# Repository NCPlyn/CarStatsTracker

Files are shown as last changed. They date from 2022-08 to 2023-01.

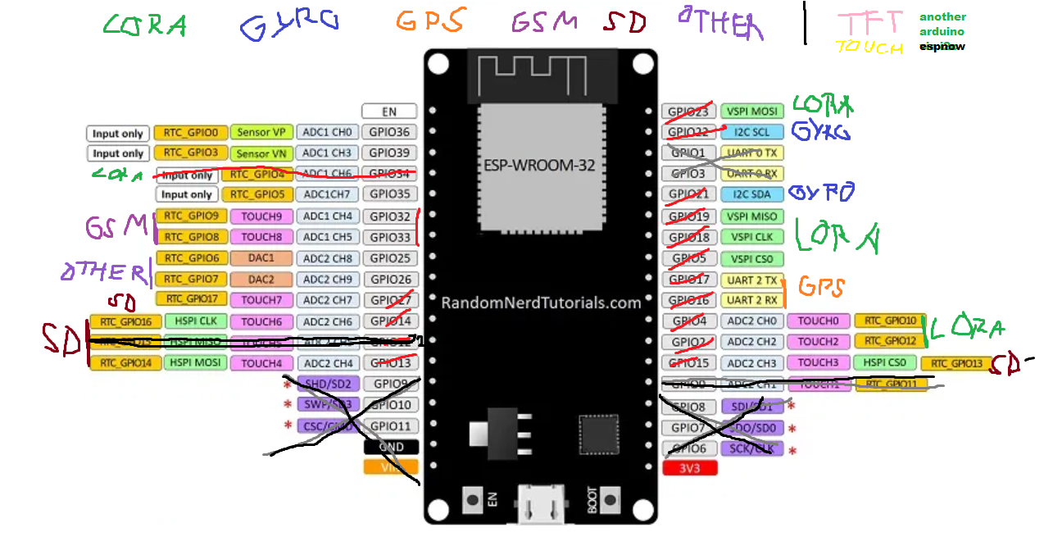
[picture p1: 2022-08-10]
PCB/pins.png

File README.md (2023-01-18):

# CarStatsTracker
Závěrečná práce\
Pro více informací použijte [dokumentaci](Dokumentace.pdf)

## Cíl projektu

Cílem projektu je vyrobit zařízení které:
- Sleduje polohu zařízení/auta pomocí GPS a posílá tyto údaje přes LoRaWAN nebo GSM na server.
- Je možno na mapě zobrazit projeté trasy s naměřenou rychlostí v bodech, ať již na serveru či lokálně na ESP.
- Možnost zjištění rychlosti akcelerace s přesností až na 200ms pomocí GPS (0-100kmph,0-60mph,1/4mile.... nastavitelné)
- Nahrání neodeslaných dat po připojení k internetu přes WiFi
- Popř. vyžádání aktuální lokace pomocí SMS zprávy a multithreading

## Použitý hardware

- ESP32 Development Board
- RA-01SH SX1276 LoRa module
- NEO-6M GPS module
- LSM6DS3 Akcelerometr module
- SD Card module, GSM module a napájecí moduly

## Použitý software a dokumentace
- LoRaWAN pro SX1276: https://github.com/beegee-tokyo/SX126x-Arduino
- TinyGPS++ pro NEO-6M: http://arduiniana.org/libraries/tinygpsplus/
- ESPAsyncWebServer pro lokání web: https://github.com/me-no-dev/ESPAsyncWebServer
- Hlavní server (Debian VPS) funguje na základě https://nodejs.org/
- spolu s základními express a socket.io knihoven, pro mapy je využit https://leafletjs.com/
- a další knihovny pro ESP\

- Byly použity návody z https://randomnerdtutorials.com/
- Dále příklady využití jednotlivých knihoven
- ArduinoJson dokumentace
- Kód z jiného projektu (https://github.com/NCPlyn/ProtogenHelmet-ESP32 & https://github.com/NCPlyn/Lidl4chan)
- Kód pro konvertování unix času (https://github.com/GyverLibs/UnixTime/blob/main/src/UnixTime.h)
- Kód pro zasunutí objektu do array (https://stackoverflow.com/questions/38418921/insert-json-object-to-ordered-array-in-javascript)
- HTTPS Wifi POST (https://github.com/espressif/arduino-esp32/tree/master/libraries/WiFiClientSecure)
- OpenSSL (https://serverfault.com/questions/845766/generating-a-self-signed-cert-with-openssl-that-works-in-chrome-58)
- MQTT pro TTN (https://youtu.be/hxIKyFAgZCE)
- EasyEDA pro vytvoření schématu a PCB

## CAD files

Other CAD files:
PCB/boxcts.f3d

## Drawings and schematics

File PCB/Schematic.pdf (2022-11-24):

LM2596

1 In +

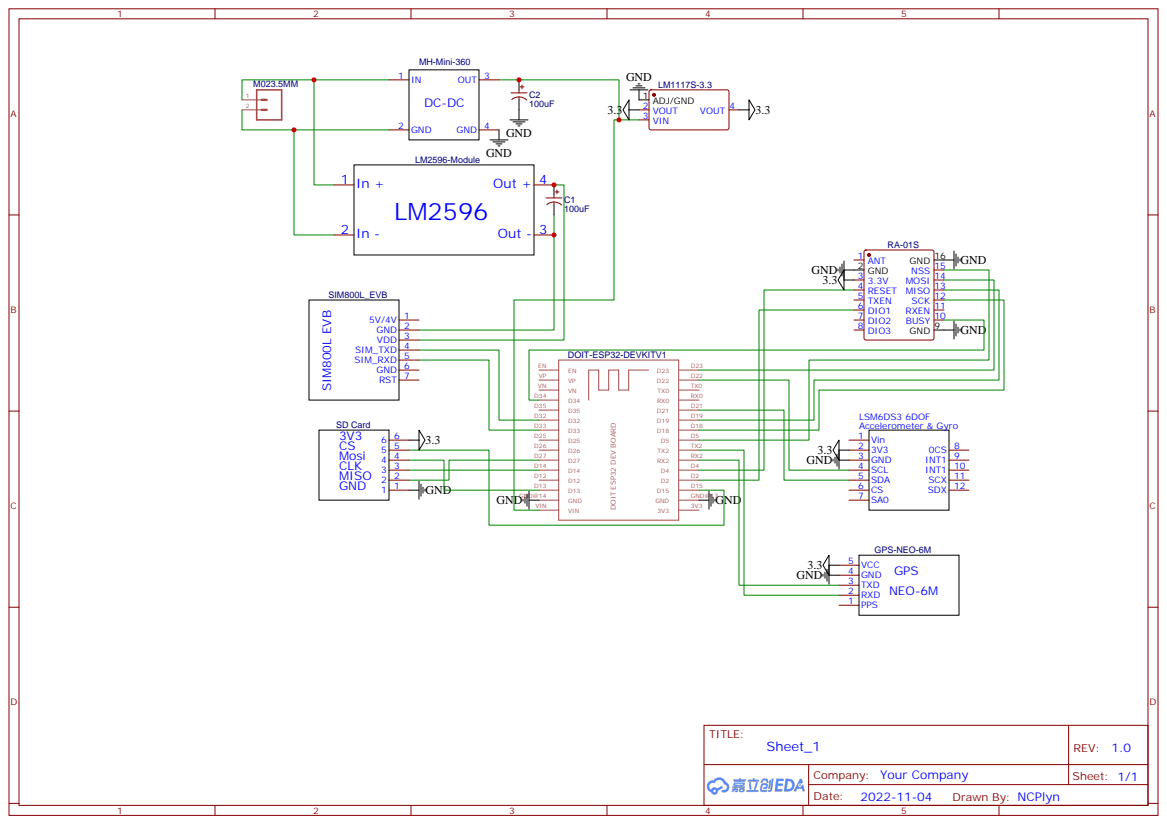
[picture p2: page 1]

BUSY 10 RXEN 11 SCK 12 MISO 13 MOSI 14 NSS 15 GND 16

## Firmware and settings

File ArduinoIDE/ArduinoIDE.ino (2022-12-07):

#include <Arduino.h>
#include <sstream>
#include <WiFi.h>
#include <HTTPClient.h>
#include <WiFiClientSecure.h>
#include <AsyncTCP.h>
#include <ESPAsyncWebServer.h>
#include "SparkFunLSM6DS3.h"
#include "Wire.h"
#include "SPI.h"
#include <TinyGPS++.h>
#include <ArduinoJson.h>
#include <ArduinoSort.h>
#include <LoRaWan-Arduino.h>
#define CONFIG_LITTLEFS_SPIFFS_COMPAT 1
#include <LittleFS.h>
#include "loraCreds.h"
#include "FS.h"
#include "SD.h"

//------------------SD CARD------------------//
#define SD_CS 15
#define SPI_SCK 14
#define SPI_MISO 27
#define SPI_MOSI 13
SPIClass SPISD(HSPI);
//Also to properly work, add "VSPI" to the () in 'SX126x-Arduino\src\boards\mcu\espressif\spi_board.cpp' on line 5

//------------------LORA------------------//
#define LORAWAN_APP_DATA_BUFF_SIZE 50 // Size of the data to be transmitted
#define JOINREQ_NBTRIALS 3  // Number of trials for the join request
hw_config hwConfig;
// Foward declaration
static void lorawan_has_joined_handler(void);
static void lorawan_join_failed_handler(void);
static void lorawan_rx_handler(lmh_app_data_t *app_data); //předdefinové, nepoužité
static void lorawan_confirm_class_handler(DeviceClass_t Class); //--||--
static void send_lora_frame(String toSend);
static uint8_t m_lora_app_data_buffer[LORAWAN_APP_DATA_BUFF_SIZE]; // Lora user application data buffer.
static lmh_app_data_t m_lora_app_data = {m_lora_app_data_buffer, 0, 0, 0, 0}; // Lora user application data structure.
static lmh_param_t lora_param_init = {LORAWAN_ADR_ON, DR_3, LORAWAN_PUBLIC_NETWORK, JOINREQ_NBTRIALS, LORAWAN_DEFAULT_TX_POWER, LORAWAN_DUTYCYCLE_OFF}; //Structure containing LoRaWan parameters, needed for lmh_init()
static lmh_callback_t lora_callbacks = {BoardGetBatteryLevel, BoardGetUniqueId, BoardGetRandomSeed, lorawan_rx_handler, lorawan_has_joined_handler, lorawan_confirm_class_handler, lorawan_join_failed_handler};//Structure containing LoRaWan callback functions, needed for lmh_init()

uint8_t nodeDeviceEUI[8], nodeAppEUI[8];
uint8_t nodeAppKey[16], nodeNwsKey[16], nodeAppsKey[16];
uint32_t nodeDevAddr;

void copyArrays() {
  memcpy(nodeDeviceEUI,STOREDnodeDeviceEUI,sizeof(STOREDnodeDeviceEUI));
  memcpy(nodeAppEUI,STOREDnodeAppEUI,sizeof(STOREDnodeAppEUI));
  memcpy(nodeAppKey,STOREDnodeAppKey,sizeof(STOREDnodeAppKey));
  memcpy(nodeNwsKey,STOREDnodeNwsKey,sizeof(STOREDnodeNwsKey));
  memcpy(nodeAppsKey,STOREDnodeAppsKey,sizeof(STOREDnodeAppsKey));
}

int loraStatus = 0; //0 off, 1 joined, 2 failed

//------------------WiFi & Web------------------//
String apName = "CST";
String apPass = "1234567890";
String staName = "todo";
String staPass = "todo";
String webAddress = "example.com/uplink";

WiFiClientSecure wifiClient;
HTTPClient httpsClient;

unsigned long wifiInterval = 0;

int lastUploaded = 0;

AsyncWebServer server(80);

void notFound(AsyncWebServerRequest *request) {
  request->send(404, "text/plain", "Not found");
}

//------------------GPS & IMU ------------------//
TinyGPSPlus gps;
TinyGPSCustom gpsFix(gps, "GPGGA", 6);

LSM6DS3 myIMU;

//------------------Variable declaration------------------//
volatile float deadzoneX=0,deadzoneY=0,deadzoneZ=0;

volatile int opMode = 0; //0 - normal, 1 - drag
int currentRideID = 0, currentDragID = 0;
bool enaLora = true; //false - GSM
float detectVal=0.4;

//------Drag------
volatile int numOfSpeeds = 0;
volatile int targetSpeeds[30] = {10};
volatile double targetSpeedsTime[30], targetSpeedsDist[30];

volatile int numOfDistances = 0;
volatile int targetDistances[30] = {100};
volatile double targetDistancesTime[30];

volatile bool dragging = false, doDrag = false, dEnded = false;
volatile double startLat = 0, startLng = 0;
volatile unsigned long startTime = 0, startTimeGPS = 0;

String dragJson;
int lastUploadedDrag = 0;

//------Normal------
unsigned long detectMoveMillis = millis(), lastLora = millis();
bool detectMove = true, moveDetected = false, routeActive = false, gpsReady = false, firstLora = true;
int retryMoveDetect = 0, didntMove = 0, loraReductor = 0;
double lastLat = 48.85826, lastLng = 2.294516;

//------Forward Declare------
void sendPos(String moving);
void calibrateAcc();
void modeSwitch(int opm);
void processDrag(bool web, char *out, unsigned long startTime, double startLat, double startLng);
void dragTimer();
void LoraSetup();

bool loadSPIFFS() {
  DynamicJsonDocument doc(512);

  File file = LittleFS.open("/config.json", "r");
  if (!file) {
    Serial.println("There was an error opening the config file!");
    file.close();
    return false;
  }
  Serial.println("Config file opened!");

  DeserializationError error = deserializeJson(doc, file);
  if (error){
    Serial.println("Failed to deserialize the config file!");
    file.close();
    return false;
  }
  file.close();

  currentRideID = doc["currentRideID"].as<int>();
  currentDragID = doc["currentDragID"].as<int>();
  lastUploaded = doc["lastUploaded"].as<int>();
  lastUploadedDrag = doc["lastUploadedDrag"].as<int>();
  enaLora = doc["enaLora"].as<bool>();
  detectVal = doc["detectVal"].as<float>();
  apName = doc["apName"].as<String>();
  apPass = doc["apPass"].as<String>();
  staName = doc["staName"].as<String>();
  staPass = doc["staPass"].as<String>();
  webAddress = doc["webAddress"].as<String>();
  return true;
}

bool saveSPIFFS() {
  DynamicJsonDocument doc(512);

  File file = LittleFS.open("/config.json", "w");
  if (!file) {
    Serial.println("There was an error opening the config file!");
    file.close();
    return false;
  }
  Serial.println("Config file opened!");

  doc["currentRideID"] = currentRideID;
  doc["currentDragID"] = currentDragID;
  doc["lastUploaded"] = lastUploaded;
  doc["lastUploadedDrag"] = lastUploadedDrag;
  doc["enaLora"] = enaLora;
  doc["detectVal"] = detectVal;
  doc["apName"] = apName;
  doc["apPass"] = apPass;
  doc["staName"] = staName;
  doc["staPass"] = staPass;
  doc["webAddress"] = webAddress;

  if (serializeJson(doc, file) == 0) {
    Serial.println("Failed to deserialize the config file");
    file.close();
    return false;
  }
  file.close();

  return true;
}

void setup() {
  Serial.begin(115200);
  delay(1000);
  Serial.println("Processor came out of reset.\n");

  if (!LittleFS.begin(true)) {
    Serial.println("An Error has occurred while mounting LittleFS");
  }

  loadSPIFFS();

  for(int x = 0;x<numOfSpeeds;x++) {
    targetSpeedsTime[x] = 0;
  }
  for(int x = 0;x<numOfDistances;x++) {
    targetDistancesTime[x] = 0;
  }

  pinMode(SD_CS, OUTPUT);
  SPISD.begin(SPI_SCK, SPI_MISO, SPI_MOSI);
  if(!SD.begin(SD_CS,SPISD)){
    Serial.println("Card Mount Failed");
  } else {
    Serial.printf("Used space: %lluMB\n", SD.usedBytes() / (1024 * 1024));
  }

  myIMU.begin();

  Serial2.begin(115200, SERIAL_8N1, 16, 17); //RX 16, TX 17

  pinMode(0, INPUT);

  WiFi.mode(WIFI_MODE_APSTA);
  WiFi.softAP(apName.c_str(), apPass.c_str());
  Serial.println(WiFi.softAPIP());
  WiFi.setAutoReconnect(false);

  server.serveStatic("/", LittleFS, "/").setDefaultFile("index.html");

  server.on("/opmode", HTTP_GET, [](AsyncWebServerRequest *request){
    if(request->hasParam("val")) {
      modeSwitch(request->getParam("val")->value().toInt());
      if(request->getParam("val")->value().toInt() == 0) {
        request->redirect("/");
      } else {
        request->redirect("/drag.html");
      }
    }
    request->send(200, "text/plain", "No param 'val'");
  });
  server.on("/doDrag", HTTP_POST, [](AsyncWebServerRequest *request){
    if(opMode == 1 && gpsReady && !doDrag && request->hasParam("json", true)) {
      calibrateAcc();
      for(int x = 0;x<30;x++){
        targetSpeeds[x] = 0;
        targetSpeedsTime[x] = 0;
        targetSpeedsDist[x] = 0;
        targetDistances[x] = 0;
        targetDistancesTime[x] = 0;
      }
      //get json and put it in global string
      dragJson = request->getParam("json", true)->value();
      //parse
      DynamicJsonDocument doc(2048);
      DeserializationError error = deserializeJson(doc, dragJson);
      if (error){
        Serial.println("Failed to deserialize json");
        request->send(200, "text/plain", "Failed to deserialize json");
      }
      //for each speed get 'target', write it to the array
      //doc["speed"][i]["targ"].as<int>()
      numOfDistances = 0;
      JsonArray distanceArray = doc["dist"];
      for (JsonObject t : distanceArray) {
        targetDistances[numOfDistances] = t["targ"].as<int>();
        numOfDistances++;
      }
      sortArray(targetDistances, numOfDistances);
      //do same for distance
      numOfSpeeds = 0;
      JsonArray speedArray = doc["speed"];
      for (JsonObject t : speedArray) {
        targetSpeeds[numOfSpeeds] = t["targ"].as<int>();
        numOfSpeeds++;
      }
      sortArray(targetSpeeds, numOfSpeeds);
      startTimeGPS = 0;
      dEnded = false;
      doDrag = true;
      Serial.println(doDrag); //musí se to přečíst nebo delay nebo co??
      request->send(200, "text/plain", "Waiting for movement/forced command");
    } else if (opMode == 0) {
      request->send(200, "text/plain", "Not in drag mode");
    } else if (!gpsReady) {
      request->send(200, "text/plain", "GPS not ready: age("+String(gps.location.age())+"), fix("+String(gpsFix.value())+"), sats("+String(gps.satellites.value())+")");
    } else {
      request->send(200, "text/plain", "Drag already in progress or other.");
    }
  });
  server.on("/forceDragStop", HTTP_GET, [](AsyncWebServerRequest *request){
    dragging = false;
    request->send(200);
  });
  server.on("/forceDragStart", HTTP_GET, [](AsyncWebServerRequest *request){
    if(opMode == 1 && gpsReady && doDrag) {
      dragTimer();
      request->send(200);
    } else if (opMode == 0) {
      request->send(200, "text/plain", "not in drag mode");
    } else if (!gpsReady) {
      request->send(200, "text/plain", "GPS not ready: age("+String(gps.location.age())+"), fix("+String(gpsFix.value())+"), sats("+String(gps.satellites.value())+")");
    } else if (!doDrag) {
      request->send(200, "text/plain", "Didn't start drag (it will sent needed data).");
    } else {
      request->send(200, "text/plain", "Drag already in progress or other.");
    }
  });
  server.on("/calibrate", HTTP_GET, [](AsyncWebServerRequest *request){
    calibrateAcc();
    request->send(200, "text/plain", "ok");
  });
  server.on("/getSpeed", HTTP_GET, [](AsyncWebServerRequest *request){
    if(gpsReady) {
      request->send(200, "text/plain", String(gps.speed.kmph()) + " km/h");
    } else {
      request->send(200, "text/plain", "GPS not ready");
    }
  });
  server.on("/getProcDrag", HTTP_GET, [](AsyncWebServerRequest *request){
    char proccesed[2048];
    processDrag(true, proccesed, startTimeGPS, startLat, startLng);
    request->send(200, "text/plain", proccesed);
  });
  server.on("/lora", HTTP_GET, [](AsyncWebServerRequest *request){
    if(request->hasParam("join")) {
      if(loraStatus == 2) {
        lmh_join();
        request->redirect("/config.html");
      } else {
        request->send(200, "text/plain", "Lora is either joined already or not initialized!");
      }
    }
    request->send(200, "text/plain", String(loraStatus));
  });
  server.on("/wifi", HTTP_GET, [](AsyncWebServerRequest *request){
    if(request->hasParam("join")) {
      if(WiFi.status() != WL_CONNECTED) {
        WiFi.disconnect();
        WiFi.begin(staName.c_str(), staPass.c_str());
        wifiInterval = millis();
        request->redirect("/config.html");
      } else {
        request->send(200, "text/plain", "WiFi is in different status than WL_CONNECTED!");
      }
    }
    request->send(200, "text/plain", String(WiFi.status()));
  });
  server.on("/getfile", HTTP_GET, [](AsyncWebServerRequest *request){
    if(request->hasParam("rideid")) {
      String path = "/"+request->getParam("rideid")->value()+".data";
      Serial.printf("Reading file: %s\n", path);
      File file = SD.open(path);
      if(!file){
          Serial.println("Failed to open file for reading");
          return;
      }
      String dataFileContents;
      while(file.available()){
          dataFileContents += (char)file.read();
      }
      file.close();
      request->send(200, "text/plain", dataFileContents);
    } else {
      request->send(200, "text/plain", "Parameter 'rideid' not present!");
    }
  });
  server.on("/getfiles", HTTP_GET, [](AsyncWebServerRequest *request){
    String out;
    File root = SD.open("/");
    if(!root){
        Serial.println("Failed to open directory");
        return;
    }

    File file = root.openNextFile();
    while(file){
        if(!file.isDirectory()){
          out += String(file.name())+";";
        }
        file = root.openNextFile();
    }
    request->send(200, "text/plain", out);
  });
  server.on("/saveconfig", HTTP_GET, [](AsyncWebServerRequest *request){ //saves config
    if(request->hasParam("enaLora"))
      std::istringstream(request->getParam("enaLora")->value().c_str()) >> std::boolalpha >> enaLora;
    if(request->hasParam("currentRideID"))
      currentRideID = request->getParam("currentRideID")->value().toInt();
    if(request->hasParam("currentDragID"))
      currentDragID = request->getParam("currentDragID")->value().toInt();
    if(request->hasParam("lastUploaded"))
      staPass = String(request->getParam("lastUploaded")->value());
    if(request->hasParam("lastUploadedDrag"))
      staPass = String(request->getParam("lastUploadedDrag")->value());
    if(request->hasParam("detectVal"))
      detectVal = String(request->getParam("detectVal")->value()).substring(0, 4).toFloat();
    if(request->hasParam("apName"))
      apName = String(request->getParam("apName")->value());
    if(request->hasParam("apPass"))
      apPass = String(request->getParam("apPass")->value());
    if(request->hasParam("staName"))
      staName = String(request->getParam("staName")->value());
    if(request->hasParam("staPass"))
      staPass = String(request->getParam("staPass")->value());
    if(request->hasParam("webAddress"))
      webAddress = String(request->getParam("webAddress")->value());
    if(saveSPIFFS()) {
      ESP.restart();
      request->redirect("/");
    } else {
      request->send(200, "text/plain", "Saving config failed!");
    }
  });

  server.onNotFound(notFound);
  server.begin();

  File file = LittleFS.open("/certificate.pem", "r");
  if (!file) {
    Serial.println("There was an error opening the certificate file!");
    file.close();
  } else {
    wifiClient.loadCACert(file,file.size());
  }

  calibrateAcc();

  if(enaLora) {
    copyArrays();
    LoraSetup();
  } else {
    //GSM init
  }
}

void loop()
{
  //GPS Serial decode
  while (Serial2.available() > 0) {
    if (gps.encode(Serial2.read())) {
      if(!gps.location.isValid() || gps.location.age() > 2000 || gpsFix.value() == 0 || gps.satellites.value() < 2) {
        gpsReady = false;
      } else {
        gpsReady = true;
      }
    }
  }

  //Main routines
  if(opMode == 0) {
    //If not moving, data to SD every 6 minutes (360000) & lora every 30 minutes (loraReductor)
    if(gpsReady && !routeActive && (millis()>lastLora+360000 || (firstLora && loraStatus == 1))) {
      Serial.println("sending not move data");
      if(firstLora && loraStatus == 1) {
        firstLora = false;
        loraReductor = 0;
        delay(200);
      }
      sendPos("n");
      lastLora = millis();
    }

    //Try to connect to WiFi & LoRa every 10 minutes (600000)
    if(millis()>(wifiInterval+600000)) {
      wifiInterval = millis();
      if(WiFi.status() != WL_CONNECTED) {
        Serial.println("Reconnecting to WiFi...");
        WiFi.disconnect();
        WiFi.begin(staName.c_str(), staPass.c_str());
      }
      if(loraStatus == 2 && enaLora) {
        lmh_join();
      }
    }

    if(WiFi.status() == WL_CONNECTED && enaLora && !routeActive ) {
      File file;
      if(lastUploaded < currentRideID) {
        file = SD.open("/"+String(lastUploaded+1)+".data");
        lastUploaded++;
        saveSPIFFS();
      } else if (lastUploadedDrag < currentDragID) {
        file = SD.open("/d"+String(lastUploadedDrag+1)+".data");
        lastUploadedDrag++;
        saveSPIFFS();
      }
      if(file){
        httpsClient.begin(wifiClient, "https://"+webAddress);
        while(file.available()){
          httpsClient.setAuthorization("admin", "admin");
          httpsClient.addHeader("Content-Type", "text/plain");
          String data = file.readStringUntil('\n');
          httpsClient.addHeader("Content-Length", String(data.length()));
          Serial.println(httpsClient.POST(data));
        }
        file.close();
        httpsClient.end();
      } else if (lastUploaded == currentRideID || lastUploadedDrag == currentDragID) {
        //do nothing
      } else {
        Serial.println("Failed to open file to send data");
      }
    }

    if(detectMove && ((myIMU.readFloatAccelX()-deadzoneX)>detectVal || (myIMU.readFloatAccelY()-deadzoneY)>detectVal || (myIMU.readFloatAccelZ()-deadzoneZ)>detectVal || (gps.speed.kmph()>5 && gpsReady))) {
      Serial.println("Movement detected");
      moveDetected = true;
      detectMove = false;
      retryMoveDetect = 0, didntMove = 0;
      detectMoveMillis = millis();
    }
    if(millis()>(detectMoveMillis+10000) && moveDetected) {
      Serial.println(gps.speed.kmph());
      if(gpsReady && gps.speed.kmph() > 5) {
        Serial.println("We movin");
        routeActive = true;
        moveDetected = false;
        currentRideID++;
        saveSPIFFS();
      } else {
        if(retryMoveDetect < 3) {
          retryMoveDetect++;
          detectMoveMillis = millis();
        } else if (retryMoveDetect > 2) {
          moveDetected = false;
          detectMove = true;
          Serial.println("Failed to move");
        }
      }
    }
    if(millis()>(lastLora+60000) && routeActive) {
      if(TinyGPSPlus::distanceBetween(gps.location.lat(),gps.location.lng(),lastLat,lastLng) < 10) {
        if(didntMove < 5) {
          Serial.println("Didnt move gps");
          didntMove++;
        } else if (didntMove > 4) {
          routeActive = false;
          detectMove = true;
        }
      } else {
        didntMove = 0;
      }
      lastLat = gps.location.lat();
      lastLng = gps.location.lng();
      sendPos("y");
      lastLora = millis();
    }
  } else if(opMode == 1) {
    if(doDrag == true) {
      if((myIMU.readFloatAccelX()-deadzoneX)>detectVal || (myIMU.readFloatAccelY()-deadzoneY)>detectVal || (myIMU.readFloatAccelZ()-deadzoneZ)>detectVal) {
        Serial.println("Movement detected");
        doDrag = false;
        dragTimer();
      }
    }
  }
}

//----------Functions----------

void fileOper(fs::FS &fs, String path, String message) {
  String msg;
  File file;
  if(fs.exists(path)) {
    file = fs.open(path, FILE_APPEND);
    msg = "append";
  } else {
    file = fs.open(path, FILE_WRITE);
    msg = "write";
  }
  if(!file){
    Serial.println("Failed to open file for "+msg);
    return;
  }
  if(file.println(message)){
    Serial.println("Data "+msg);
  } else {
    Serial.println("Failed data "+msg);
  }
  file.close();
}

uint32_t getUnix(uint32_t year, uint32_t month, uint32_t day, uint32_t hour, uint32_t minute, uint32_t second) {
  int8_t my = (month >= 3) ? 1 : 0;
  uint16_t y = year + my - 1970;
  uint16_t dm = 0;
  for (int i = 0; i < month - 1; i++) dm += (i<7)?((i==1)?28:((i&1)?30:31)):((i&1)?31:30);
  return (((day-1+dm+((y+1)>>2)-((y+69)/100)+((y+369)/100/4)+365*(y-my))*24ul+hour)*60ul+minute)*60ul+second;
}

void sendPos(String moving) { //rideid;moving;lat;lng;kmph;epoch
  String out = String(currentRideID)+";"+moving+";"+String(gps.location.lat(),5)+";"+String(gps.location.lng(),5)+";"+String(gps.speed.kmph())+";"+String(getUnix(gps.date.year(),gps.date.month(),gps.date.day(),gps.time.hour(),gps.time.minute(),gps.time.second()));
  Serial.println(out);
  fileOper(SD,"/"+String(currentRideID)+".data",out);
  if(enaLora && loraStatus == 1) {
    if (loraReductor == 0) {
      send_lora_frame(out);
      loraReductor = 5;
    } else {
      loraReductor--;
    }
  } else { //gsm ready
    //GSM send
  }
}

void calibrateAcc() {
  Serial.println("Stay still, calibrating...");
  for(int x = 0; x<5; x++) {
    deadzoneX+=myIMU.readFloatAccelX();
    deadzoneY+=myIMU.readFloatAccelY();
    deadzoneZ+=myIMU.readFloatAccelZ();
    delay(10);
  }
  deadzoneX=deadzoneX/5;
  deadzoneY=deadzoneY/5;
  deadzoneZ=deadzoneZ/5;
  Serial.println("Calibration done");
}

void modeSwitch(int opm) {
  if(opMode == 0 && opm == 1) {
    routeActive = false;
    detectMove = true;
    didntMove = 0;
    opMode = 1;
  } else if (opMode == 1 && opm == 0) {
    doDrag = false;
    dragging = false;
    opMode = 0;
    calibrateAcc();
  }
}

double round2(double value) {
   return (int)(value * 100 + 0.5) / 100.0;
}
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

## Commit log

2022-11-08 Drag web & fixes
    [beta.ino]
2022-11-24 Clean up
    [boxcts.f3d, no_ota.csv]
